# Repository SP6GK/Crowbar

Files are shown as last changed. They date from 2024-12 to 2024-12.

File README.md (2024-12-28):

# **Overvoltage Protection Circuit**

This circuit is designed for **overvoltage protection** of amateur radio transceivers, which are typically powered by 13.8 V DC with a current of 20 to 25 A.

---

## **Specification**

- **Default tripping voltage**: 14.7 V  
- **Action time**: < 15 µs (typical ~µ4 s)  
- **Rated current**: Max 25 A
- **Dimension**: 94x59 mm

---

## **Description**

The protection is achieved by **shorting the power supply**, which should blow a fuse and prevent expensive equipment from experiencing a voltage spike. The tripping voltage is approximately **14.7 V**, but it can be adjusted by replacing the Zener diode.  

For **low idle current** and **fast activation** of the triac's gate, the circuit uses an additional transistor in a configuration similar to a Zener-NPN regulator.  

The PCB features space for **M5 screw terminals**, but wires can also be soldered directly and four M3 mounting screws.

> **Recommended Use:**  
> This circuit is especially useful for linear power supplies. In the event of a final transistor(s) fault, a short between the emitter and collector could result in the full rectified voltage being present at the output, which would exceed 13.8 V.  

---

## **PCB Layout**

Below is the layout of the PCB:  

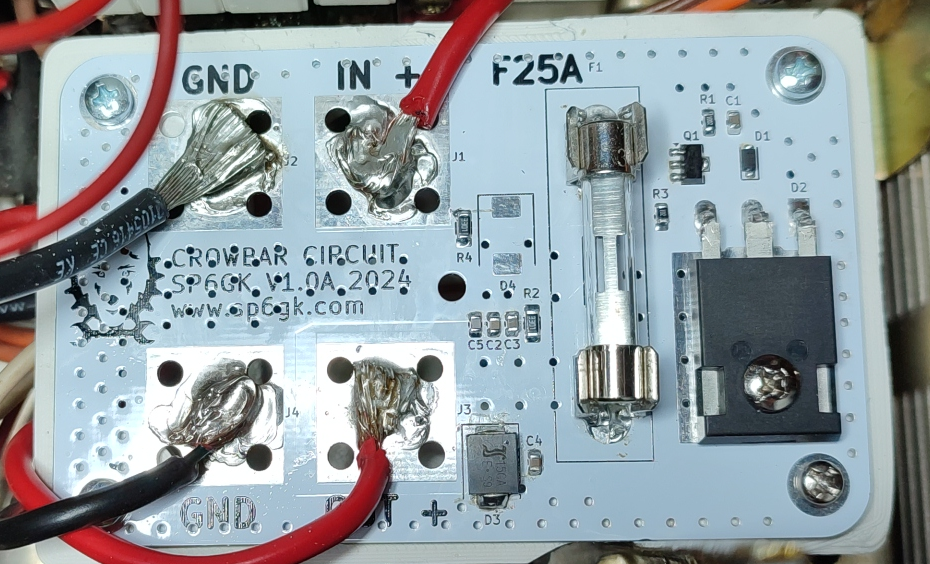
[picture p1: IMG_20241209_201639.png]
PCB Installed in Yaesu FT-107E
  

---

## **Oscilloscope Screenshots**

The oscilloscope captures below demonstrate the **input (blue, CH2)** and **output (yellow, CH1)** when a sudden 20 V was applied using two parallel 5 A power supplies.  

> Generating consistent transients was challenging, but these scenarios show how the circuit prevented the voltage rail from ramping up and successfully clamped the voltage.  

1. **Transient 1**  
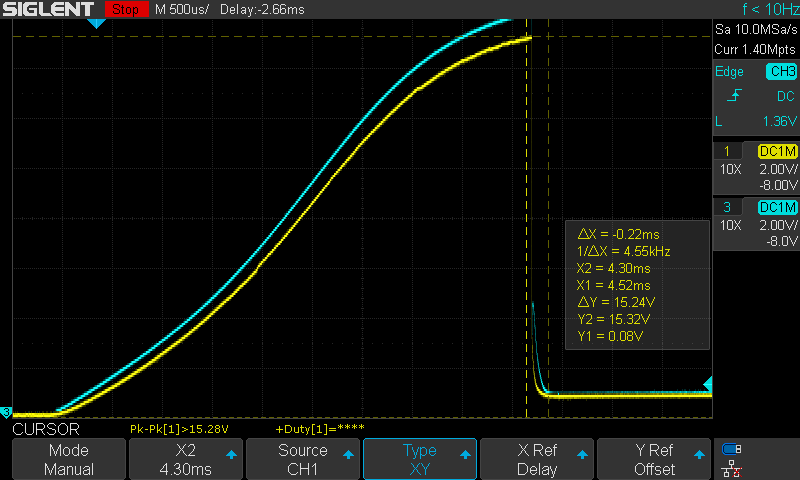
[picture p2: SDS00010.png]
Transient 1
   

2. **Transient 2**  
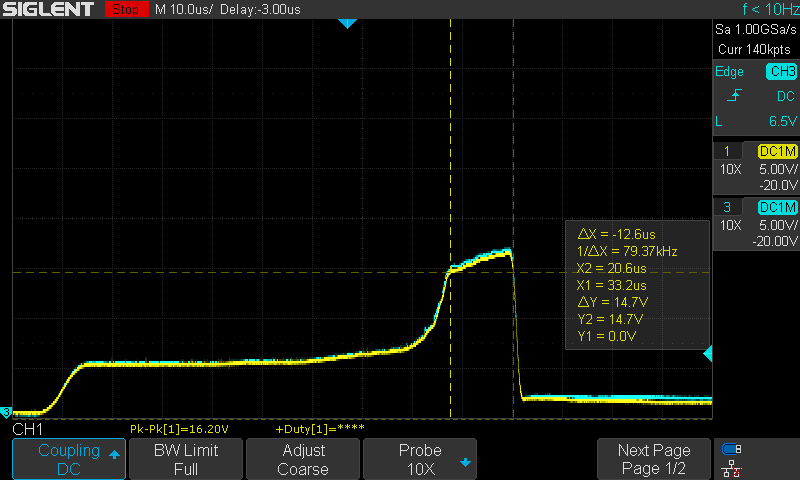
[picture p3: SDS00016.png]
Transient 2
   

3. **Transient 3**  
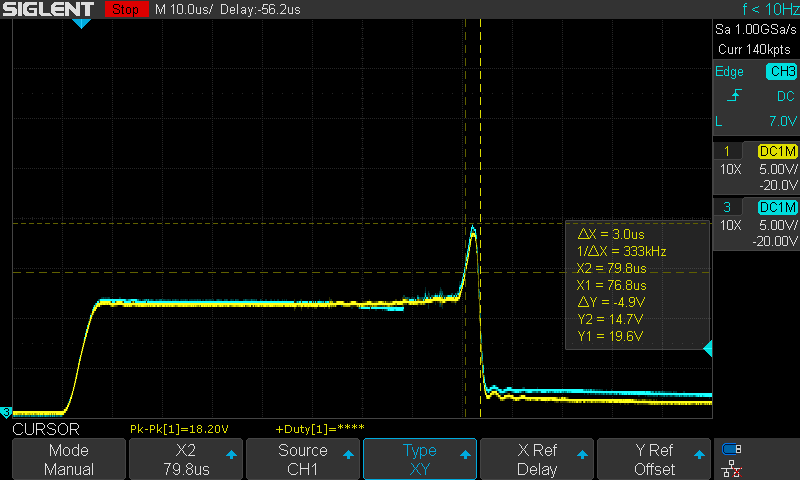
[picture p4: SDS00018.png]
Transient 3


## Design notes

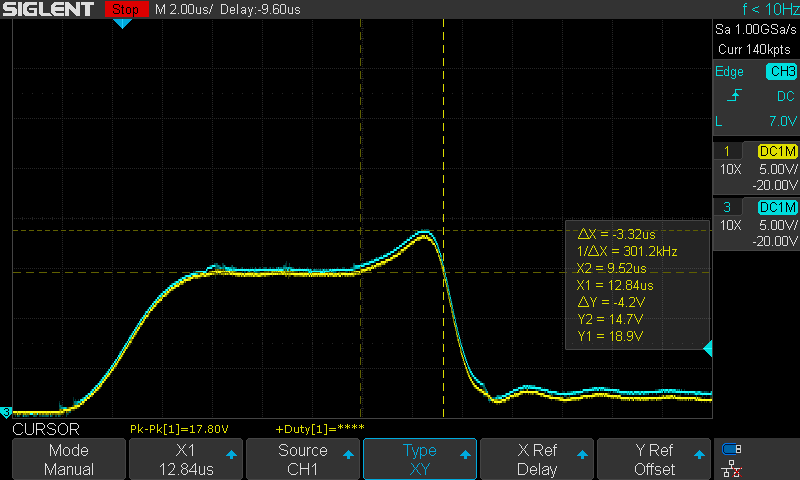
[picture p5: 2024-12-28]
SDS00019.png

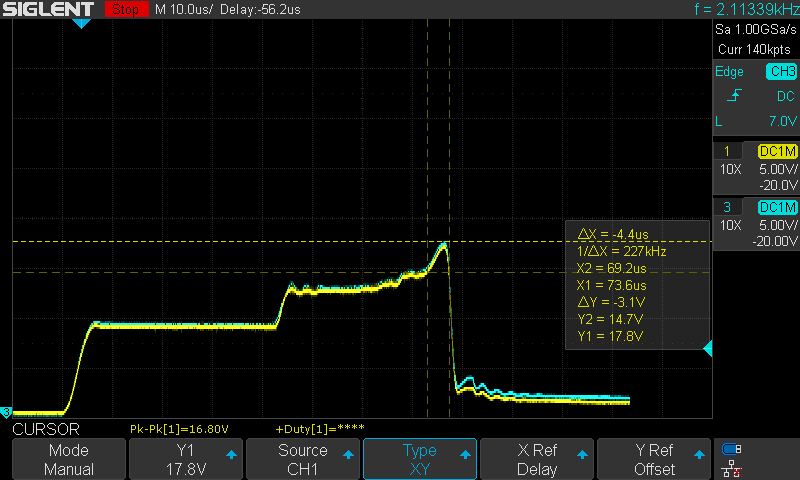
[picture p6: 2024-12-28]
SDS00017.png

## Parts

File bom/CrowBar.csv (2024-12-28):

Reference | Value | Datasheet | Footprint | Qty | DNP | Note
C1,C2,C4 | 100n | ~ | Capacitor_SMD:C_0805_2012Metric | 3 |  | https://www.tme.eu/pl/en/details/cl21b104kcfsfne/mlcc-smd-capacitors/samsung/
C3 | 1u | ~ | Capacitor_SMD:C_0805_2012Metric | 1 |  | https://www.tme.eu/pl/en/details/08051c105k4t2a/mlcc-smd-capacitors/kyocera-avx/
C5 | 10n | ~ | Capacitor_SMD:C_0805_2012Metric | 1 |  | https://www.tme.eu/pl/en/details/c0805c103k1rac/mlcc-smd-capacitors/kemet/c0805c103k1ractu/
D1 | 15V | https://www.tme.eu/Document/65a69b9cbbd99051440c14d1a6fe3b92/mm1z4689.pdf | Diode_SMD:D_SOD-123F | 1 |  | https://www.tme.eu/pl/en/details/mm1z4702-dio/smd-zener-diodes/diotec-semiconductor/mm1z4702/
D2 | BT155W | https://www.tme.eu/Document/c7049c1e04abe08c3b6b28cdbf67d72e/BT155W-1200T-AQ.pdf | Package_TO_SOT_THT:TO-247-3_Horizontal_TabDown | 1 |  | https://www.tme.eu/pl/en/details/bt155w-1200t-aq/smd-tht-thyristors/ween-semiconductors/
D3 | 1.5SMCJ15CA | https://diotec.com/request/datasheet/15smcj65.pdf | Diode_SMD:D_SMC | 1 |  | https://www.tme.eu/pl/en/details/1.5smcj15ca-dio/bidirectional-tvs-smd-diodes/diotec-semiconductor/1-5smcj15ca/
F1 | 25 A Fast | ~https://www.tme.eu/Document/a5a5f9439f5247c7e6a4b49e4e756560/LittelFuse_Seria_0312.pdf | Fuse_custom:8040.0001SCHURTER | 1 |  | https://www.tme.eu/pl/en/details/0312025.mxp/fuses-6-3x32mm-fast/littelfuse/
J1,J2,J3,J4 | AMT0450001DB0000G | ~https://www.tme.eu/Document/e5174bcdf1174710a2c2984d31ca4cbf/AMT45001DB.pdf | ScrewTerminal_custom:AMT0450001DB0000G | 4 |  | https://www.tme.eu/pl/en/details/amt0450001db0000g/pcb-terminal-blocks/amphenol-anytek/
Q1 | BCX56 | https://assets.nexperia.com/documents/data-sheet/BCX56_SER.pdf | Package_TO_SOT_SMD:SOT-89-3 | 1 |  | https://www.tme.eu/pl/en/details/bcx56-16.135/npn-smd-transistors/nexperia/bcx56-16-135/
R1 | 1k | ~ | Resistor_SMD:R_0805_2012Metric_Pad1.20x1.40mm_HandSolder | 1
R2,R4 | 4k7 | ~ | Resistor_SMD:R_1206_3216Metric_Pad1.30x1.75mm_HandSolder | 2
R3 | 10k | ~ | Resistor_SMD:R_0805_2012Metric_Pad1.20x1.40mm_HandSolder | 1

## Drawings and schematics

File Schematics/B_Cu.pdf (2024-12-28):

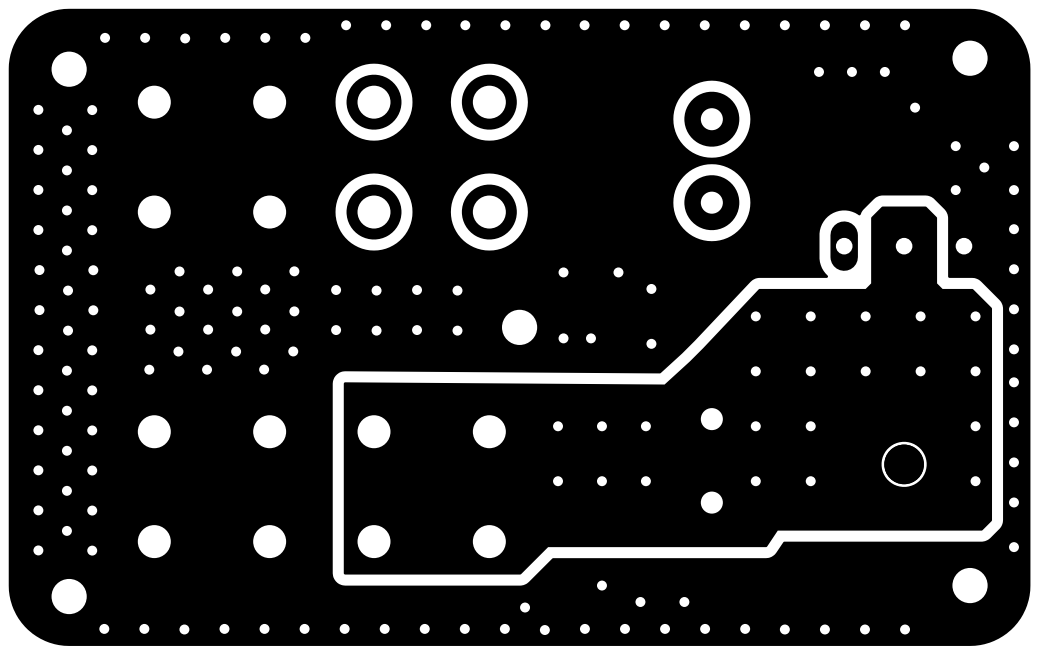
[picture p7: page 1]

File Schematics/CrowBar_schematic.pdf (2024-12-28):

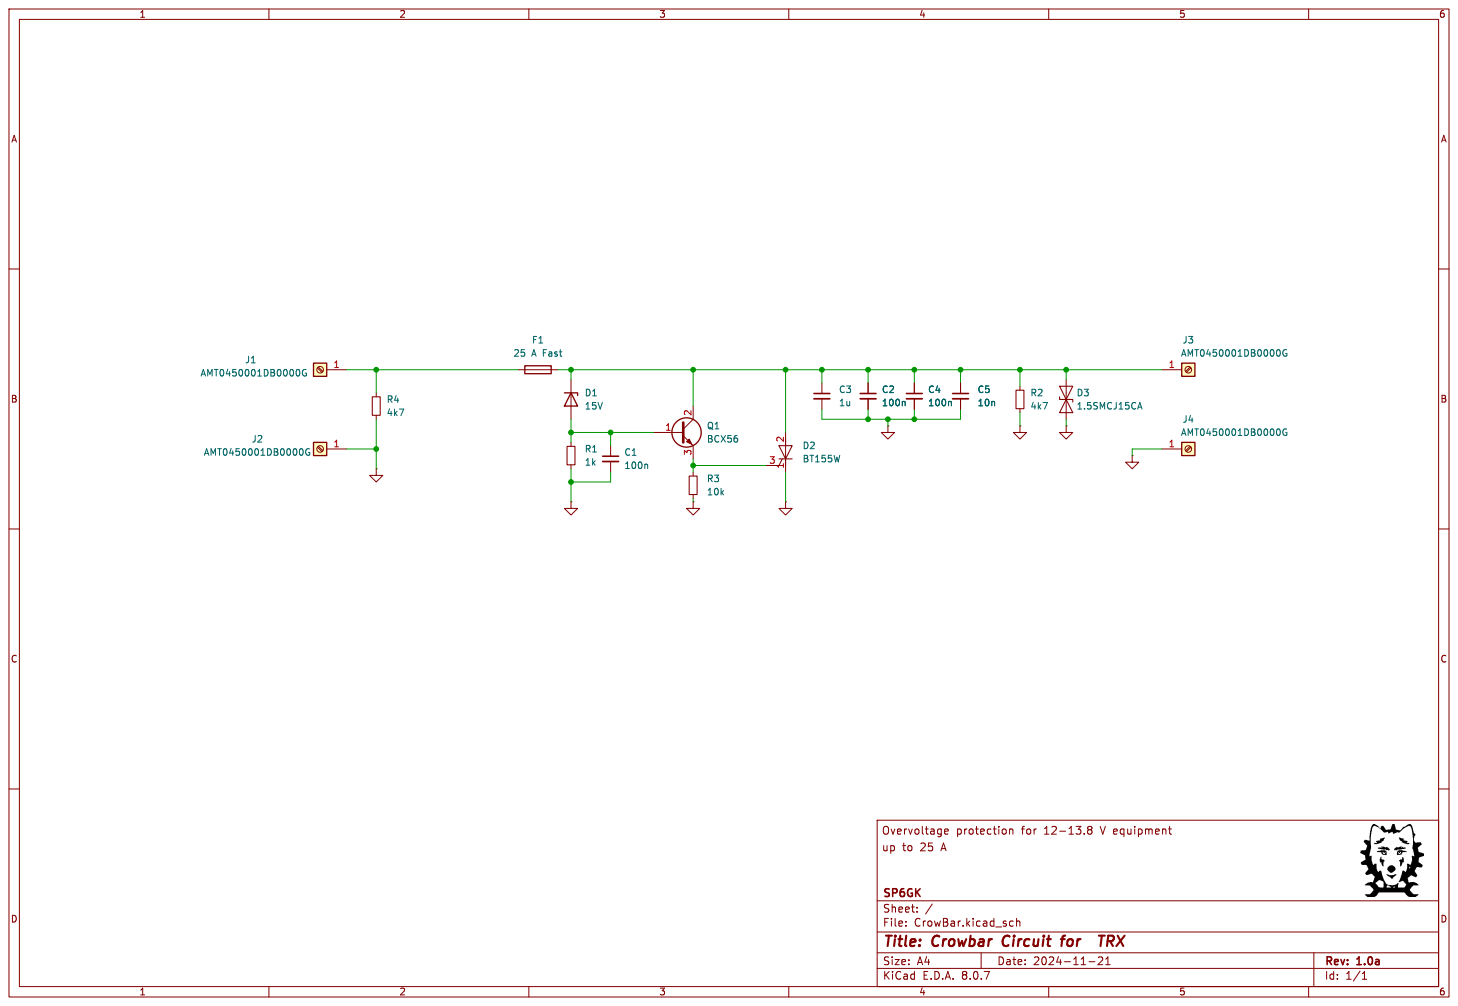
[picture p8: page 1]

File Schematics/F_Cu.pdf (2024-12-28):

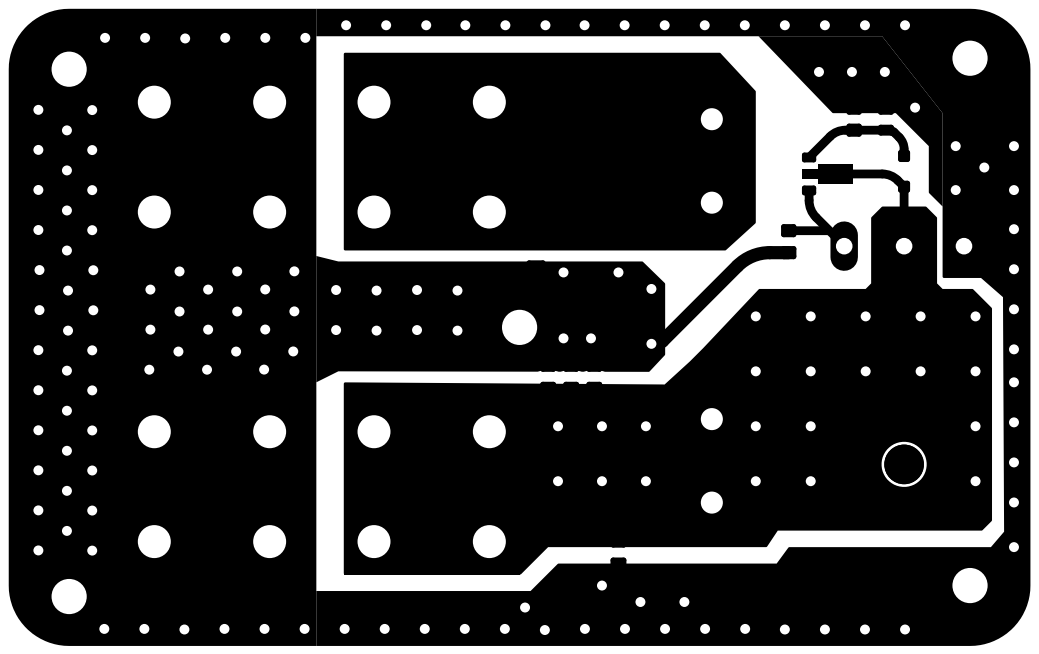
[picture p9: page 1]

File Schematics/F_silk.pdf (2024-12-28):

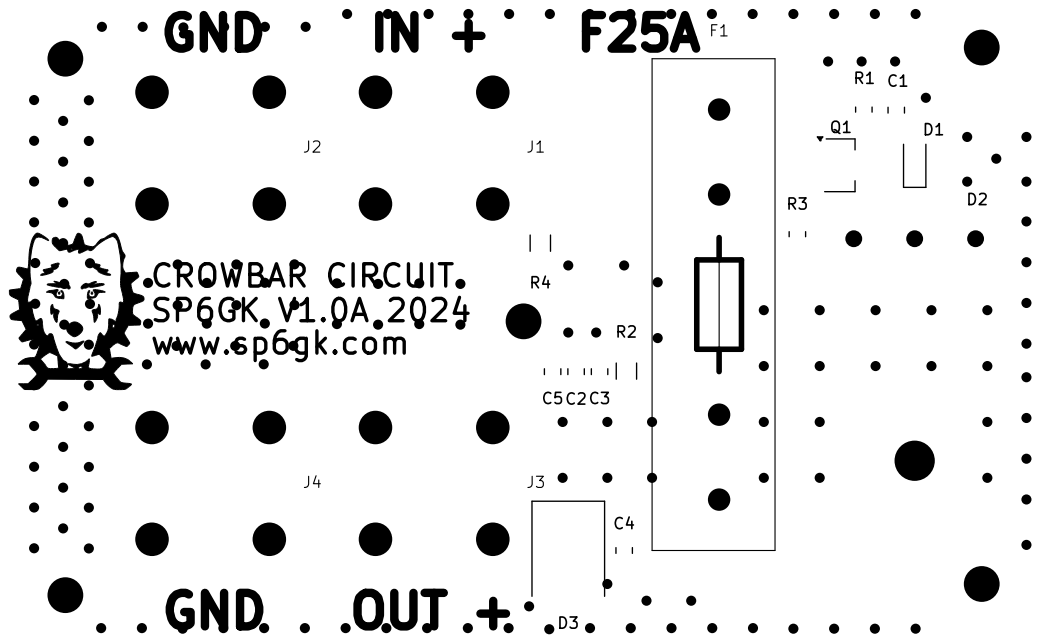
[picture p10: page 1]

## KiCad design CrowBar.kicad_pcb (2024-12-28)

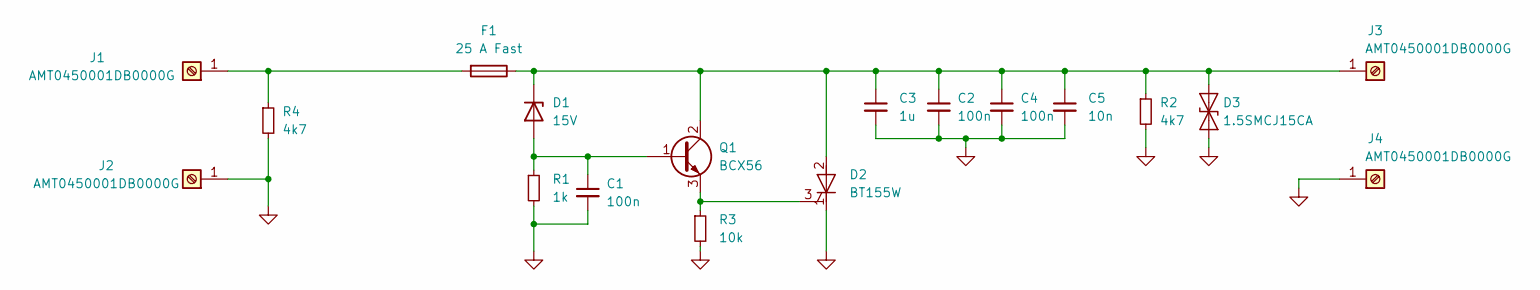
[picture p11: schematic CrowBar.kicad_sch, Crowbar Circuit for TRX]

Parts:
C1, C2, C4: 100n; C_0805_2012Metric
C3: 1u; C_0805_2012Metric
C5: 10n; C_0805_2012Metric
D1: 15V; D_SOD-123F
D2: BT155W; TO-247-3_Horizontal_TabDown
D3: 1.5SMCJ15CA; D_SMC
F1: 25 A Fast; 8040.0001SCHURTER
J1, J2, J3, J4: AMT0450001DB0000G
Q1: BCX56; SOT-89-3
R1: 1k; R_0805_2012Metric_Pad1.20x1.40mm_HandSolder
R2, R4: 4k7; R_1206_3216Metric_Pad1.30x1.75mm_HandSolder
R3: 10k; R_0805_2012Metric_Pad1.20x1.40mm_HandSolder

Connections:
GND: C1.2, C2.2, C3.2, C4.2, C5.2, D2.1 (K), D3.2 (A2), J2.1, J4.1, R1.2, R2.2, R3.2, R4.2
unnamed: C1.1, D1.2 (A), Q1.1 (B), R1.1
unnamed: C2.1, C3.1, C4.1, C5.1, D1.1 (K), D2.2 (A), D3.1 (A1), F1.1, J3.1, Q1.2 (C), R2.1
unnamed: D2.3 (G), Q1.3 (E), R3.1
unnamed: F1.2, J1.1, R4.1

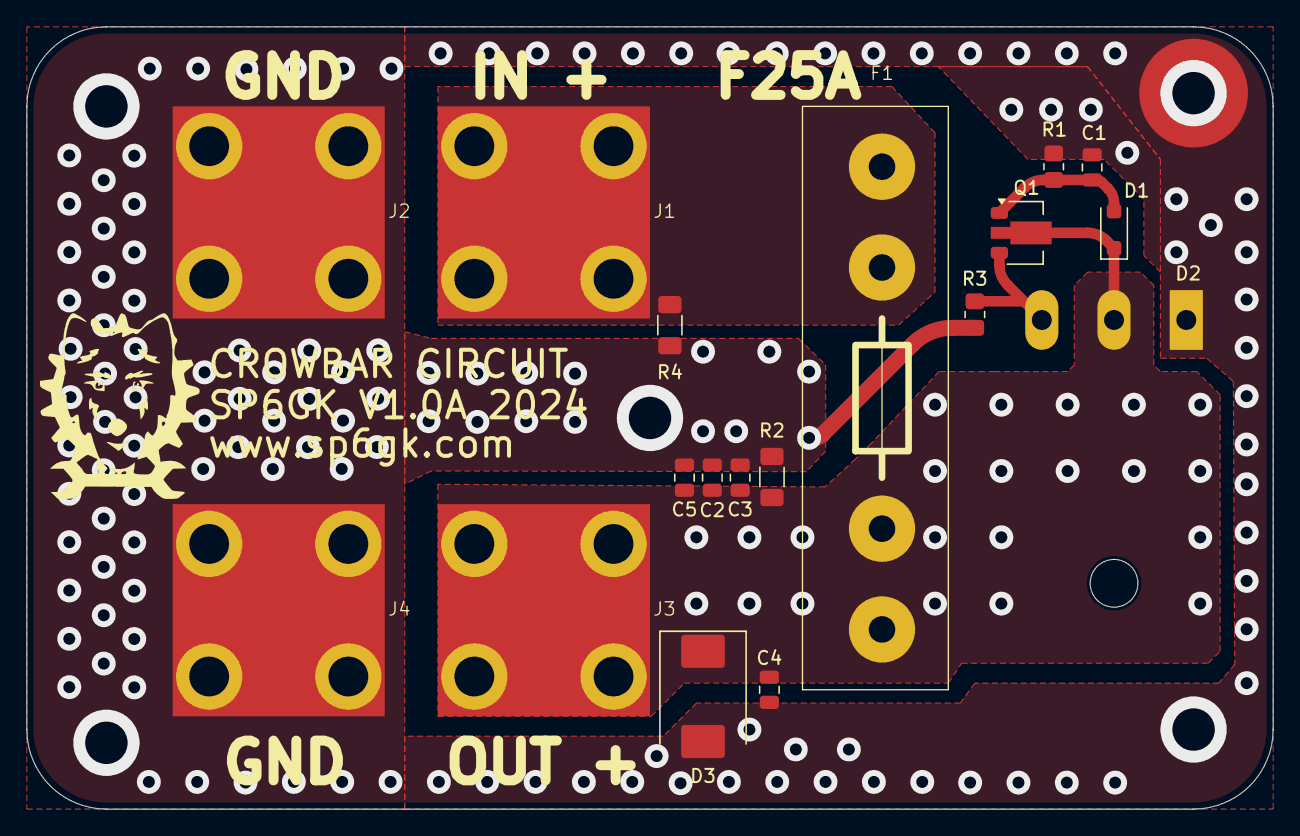
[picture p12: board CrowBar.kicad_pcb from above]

Board: 2 copper layers, 94.0 x 59.0 mm, 18 parts (0 on the bottom side), 5 nets.
